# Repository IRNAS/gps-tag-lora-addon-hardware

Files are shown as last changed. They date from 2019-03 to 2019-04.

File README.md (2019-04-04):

irnas_logo

# gps-tag-lora-addon-hardware
Addon board with LoRa module for gps tag

Features:
* MCU STM32L072CZ
* USB
* on-board LDO regulator
* EEPROM with EUI Microchip 24AA02E48T-I/OT
* LoRa module E22-900M22S (SX1268)
* on-board SMT LoRa antenna

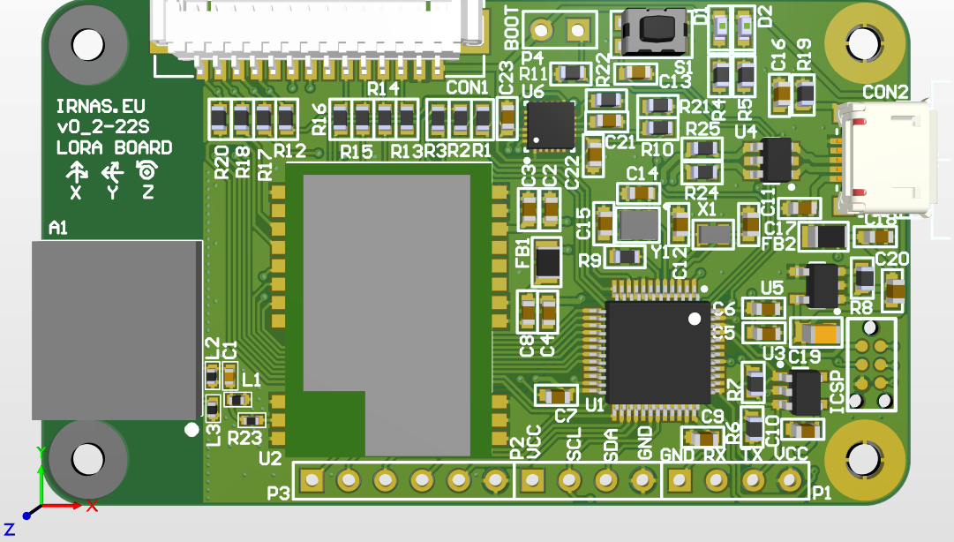
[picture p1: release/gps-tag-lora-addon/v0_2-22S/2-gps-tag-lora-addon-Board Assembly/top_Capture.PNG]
board_model


For all documentation please find the [latest relase](https://github.com/IRNAS/gps-tag-lora-addon-hardware/releases).

---
## License

All our projects are as usefully open-source as possible.

Hardware including documentation is licensed under [CERN OHL v.1.2. license](http://www.ohwr.org/licenses/cern-ohl/v1.2)

Firmware and software originating from the project is licensed under [GNU GENERAL PUBLIC LICENSE v3](http://www.gnu.org/licenses/gpl-3.0.en.html).

Open data generated by our projects is licensed under [CC0](https://creativecommons.org/publicdomain/zero/1.0/legalcode).

All our websites and additional documentation are licensed under [Creative Commons Attribution-ShareAlike 4 .0 Unported License] (https://creativecommons.org/licenses/by-sa/4.0/legalcode).

What this means is that you can use hardware, firmware, software and documentation without paying a royalty and knowing that you'll be able to use your version forever. You are also free to make changes but if you share these changes then you have to do so on the same conditions that you enjoy.

Koruza, GoodEnoughCNC and IRNAS are all names and marks of Institut IRNAS Rače. 
You may use these names and terms only to attribute the appropriate entity as required by the Open Licences referred to above. You may not use them in any other way and in particular you may not use them to imply endorsement or authorization of any hardware that you design, make or sell.

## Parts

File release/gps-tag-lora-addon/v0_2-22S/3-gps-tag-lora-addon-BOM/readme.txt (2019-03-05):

This folder includes:
- irnas readble BOM
- irnas simple sticker BOM

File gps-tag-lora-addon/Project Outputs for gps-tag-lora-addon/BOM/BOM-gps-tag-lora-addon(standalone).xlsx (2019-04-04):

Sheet: Part List Report
 | Component list |  |  | Arribada turtle gps tag Lora
 | Source Data From: | gps-tag-lora-addon.PrjPcb |  |  | Contact:
 | Project: | gps-tag-lora-addon.PrjPcb
 | Variant: | standalone |  |  |  |  |  |  | IRNAS
 | Report Date: | 04/04/2019 | 1:00 PM |  |  |  |  |  | www.irnas.eu
 | Print Date: | 2019-04-04 | 13:00:18
# | Manufacturer Part Number 1 | Manufacturer 1 | Description | Footprint | Designator | Quantity | Supplier 1 | Supplier Part Number 1 | Supplier Order Qty 1 | Supplier Stock 1 | Supplier Unit Price 1 | Supplier Subtotal 1 | Supplier Currency 1
1 | CC0805KKX7R8BB225 | Yageo | Multilayer Ceramic Capacitors MLCC - SMD/SMT 2.2uF 25V X7R 10% | CAP0805 | C19 | 1 | Farnell | 1458904 | 10 | 41834 | 0.37 | 3.73 | EUR
2 | 0603N331J500CT | Walsin Technologies | Cap Ceramic 330pF 50V C0G 5% SMD 0603 125C Paper T/R | CAP0603 | C16 | 1 | Farnell | 2496902 | 10 | 11708 | 0.08 | 0.75 | EUR
3 | TPS78326DDCT | Texas Instruments | IC REG LINEAR 2.6V 150MA SOT23-5 | SOT95P280X145-5N | U5 | 1 | Digi-Key | 296-35542-1-ND | 10 | 873 | 0.76 | 7.62 | EUR
4 | MPU-9250 | TDK InvenSense | IMU ACCEL/GYRO/MAG I2C/SPI 24QFN | QFN40P300X300X105_HS-25N | U6 | 1 | RSComponents | 883-7942P |  | 0
5 | C0603X103K5RECAUTO | TDK EPCOS | KEMET - C0603X103K5RECAUTO - CAP, MLCC, AEC-Q200, X7R, 0.01UF, 50V | CAP0603 | C22 | 1 | Farnell | 2760492 |  | 0
6 | STM32L072CZT6 | STMicroelectronics | IC MCU 32BIT 192KB FLASH 48LQFP | TSQFP50P900X900X160-48N | U1 | 1 | Mouser | 511-STM32L072CZT6 | 10 | 1017 | 3.13 | 31.30 | EUR
7 | USBLC6-2SC6 | STMicroelectronics | TVS DIODE 5.25VWM 17VC SOT23-6 | SOT95P280X145-6N | U4 | 1 | Farnell | 1269406 | 10 | 34596 | 0.38 | 3.83 | EUR
8 | BLM21PG221SN1D | Murata | FERRITE CHIP 220 OHM 0805 | IND0805 | FB1, FB2 | 2 | Farnell | 1515661 | 20 | 96225 | 0.06 | 1.20 | EUR
9 | LQG15HN4N3S02D | Murata | Inductor RF Chip Multi-Layer 4.3nH 0.3nH 100MHz 8Q-Factor Air 300mA 210mOhm DCR 0402 Paper T/R | IND0402 | L3 | 1 | Digi-Key | 490-6563-1-ND | 10 | 3502 | 0.05 | 0.54 | EUR
10 | GJM1555C1H2R2WB01D | Murata | Multilayer Ceramic Capacitors MLCC - SMD/SMT 0402 2.2pF 50Volts C0G +/-0.05pF | CAP0402 | C1 | 1 | Farnell | 2781431 | 10 | 0 | 0.23 | 2.30 | EUR
11 | GRM188R61H105KAALD | Murata | MURATA - GRM188R61H105KAALD - CAP, MLCC, X5R, 1UF, 50V, 0603 | CAP0603 | C3, C4, C5, C20 | 4 | Farnell | 1845736 | 40 | 0 | 0.41 | 16.42 | EUR
12 | GRM188R71C104KA01J | Murata | MURATA - GRM188R71C104KA01J - CAP, MLCC, X7R, 0.1UF, 16V, 0603 | CAP0603 | C2, C6, C7, C8, C9, C10, C13, C17, C18, C21, C23 | 11 | Farnell | 2688519 |  | 0
13 | GRM1885C1H200JA01D | Murata | MURATA - GRM1885C1H200JA01D - CAPACITOR, MLCC, C0G, 20PF, 50V, 0603 | CAP0603 | C11, C12, C14, C15 | 4 | Farnell | 2456108 | 40 | 0 | 0.09 | 3.64 | EUR
14 | MCWR06X27R0FTL | Multicomp | MULTICOMP MCWR06X27R0FTL Surface Mount Chip Resistor, Thick Film, MCWR Series, 27 ohm, 100 mW, 1%, 50 V | RES0603 | R24, R25 | 2 | Farnell | 2447316 | 20 | 74640 | 0.01 | 0.12 | EUR
15 | MC0.063W06031%1M | Multicomp | MULTICOMP - MC0063W060311M - RES, THICK FILM, 1M, 1%, 0.063W, 0603 | RES0603 | R19 | 1 | Farnell | 9330410 | 10 | 0 | 0.08 | 0.80 | EUR
16 | MCMR06X103JTL | Multicomp | MULTICOMP - MCMR06X103 JTL - RES, CERAMIC, 10K, 5%, 0.1W, 0603 | RES0603 | R8, R11, R22 | 3 | Farnell | 2073356 |  | 0
17 | MCMR06X471JTL | Multicomp | MULTICOMP - MCMR06X471 JTL - RES, CERAMIC, 470R, 5%, 0.1W, 0603 | RES0603 | R4, R5 | 2 | Farnell | 2073513 | 20 | 3705 | 0.01 | 0.12 | EUR
18 | MCMR06X4701FTL | Multicomp | MULTICOMP - MCMR06X4701FTL - RES, CERAMIC, 4K7, 1%, 0.1W, 0603 | RES0603 | R6, R7 | 2 | Farnell | 2073509 | 20 | 21438 | 0.01 | 0.22 | EUR
19 | MCWR06X2200FTL | Multicomp | MULTICOMP - MCWR06X2200FTL - RES, THICK FILM, 220R, 1%, 0.1W, 0603 | RES0603 | R9 | 1 | Farnell | 2447298 | 10 | 114827 | 0.01 | 0.06 | EUR
20 | MCMR04X000PTL | Multicomp | RESISTOR, 0402, 0R, ANTI SULFURATION | RES0402 | R23 | 1 | Farnell | 2072513 | 10 | 222051 | 0.01 | 0.07 | EUR
21 | 53261-1471 | Molex | 1.25mm (.049") Pitch PicoBlade Header, Surface Mount, Right Angle, Lead-free, 14 Circuits | 53261-1471 | CON1 | 1 | Farnell | 1125364 | 10 | 2483 | 2.04 | 20.36 | EUR
22 | 24AA02E48T-I/OT | Microchip | MICROCHIP 24AA02E48T-I/OT EEPROM, EUI-48 Node Identity, 2 Kbit, 2 BLK (128K x 8bit), 400 kHz, I2C, SOT-23, 5 Pins | SOT95P280X145-5N | U3 | 1 | Farnell | 1688855 | 10 | 10048 | 0.20 | 2.00 | EUR
23 | KMR221NGLFS | ITT C&K | SWITCH TACTILE SPST-NO 0.05A 32V | SW | S1 | 1 | Farnell | 2845727 | 10 | 2438 | 0.34 | 3.40 | EUR
24 | HSMS-C190 | Broadcom | BROADCOM LIMITED - HSMS-C190 - LED, RED, 10MCD, 626NM | LED0603 | D1, D2 | 2 | Farnell | 2497356 | 20 | 0 | 0.15 | 2.90 | EUR
25 | CR0603-J/-000ELF | Bourns | BOURNS - CR0603-J/-000ELF - RES, THICK FILM, 0R, 5%, 0.1W, 0603 | RES0603 | R1, R2, R3, R10, R12, R17, R18, R20, R21 | 9 | Farnell | 2008343 | 90 | 36437 | 0.01 | 1.25 | EUR
26 | SR42I010-R | Antenova | Antenna SMD -4dBi Gain 870MHz/928MHz Automotive 7-Pin SMD T/R | LORA_PCB_ANTENNA | A1 | 1 | Mouser | 237-SR42I010-R | 10 | 2899 | 1.69 | 16.90 | EUR
27 | ABM10-16.000MHZ-D30-T3 | Abracon | 16MHz ±20ppm Crystal 10pF 150 Ohm -40°C ~ 85°C Surface Mount 4-SMD, No Lead (DFN, LCC) | CRY2.5X2 | Y1 | 1 | Farnell | 2467762 | 10 | 1307 | 1.17 | 11.67 | EUR
28 | ABS06-107-32.768KHZ-T | Abracon | 32.768KHz 4pF Max. ESR 81 Kohms | CRY2X1.2 | X1 | 1 | Farnell | 2467860 | 10 | 5308 | 0.77 | 7.66 | EUR
29 |  |  |  | microUSB-CHINA | CON2 | 1
30 |  |  |  | E22-900M22S | U2 | 1
 |  |  |  |  |  | 61 |  |  | 430 |  |  | 138.86673
Approved |  |  |  | Notes
 |  |  |  | pcs: |  | 10 |  | Total |  | 138.86673 |  | EUR
 |  |  |  |  |  |  |  | Price for 1pcs |  | 13.89 |  | EUR

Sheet: Project Information
Project Full Path | C:\Users\vojislav\OneDrive\IRNAS-Common\_NEW-IRNAS-COMMON\opencollar-io\Electronics\gps-tag-lora-addon-hardware\gps-tag-lora-addon\gps-tag-lora-addon.PrjPcb
Project Filename | gps-tag-lora-addon.PrjPcb
Variant Name | standalone
Data-Source Filename | gps-tag-lora-addon.PrjPcb
Data-Source Full Path | C:\Users\vojislav\OneDrive\IRNAS-Common\_NEW-IRNAS-COMMON\opencollar-io\Electronics\gps-tag-lora-addon-hardware\gps-tag-lora-addon\gps-tag-lora-addon.PrjPcb
Title | BOM for Variant [standalone] of Project [gps-tag-lora-addon.PrjPcb] (PCB Document : gps-tag-lora-addon.PcbDoc)
Total Quantity | 61
Report Time | 1:00 PM
Report Date | 04/04/2019
Report Date & Tine | 04/04/2019 1:00 PM
Output Name | BOM
Output Type | BOM_PartType
Output Generator Name | BOM
Output Generator Description | Bill of Materials

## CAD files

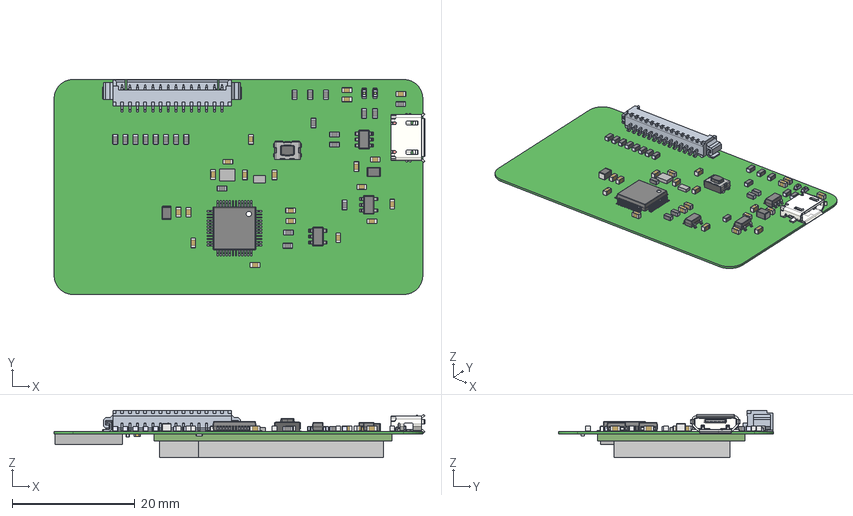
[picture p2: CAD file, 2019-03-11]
gps-tag-lora-addon/Project Outputs for gps-tag-lora-addon/ExportSTEP/gps-tag-lora-addon(standalone).step
60.3 x 35.0 x 7.69 mm
R0603 x 21
Mid_Body
Open_CASCADE_STEP_translator_6.8_3.2.1 x 2
Mark
Open_CASCADE_STEP_translator_6.8_1.1.1 x 3
Leader x 64
Open_CASCADE_STEP_translator_6.8_6.1.1
Extruded x 7
Open_CASCADE_STEP_translator_6.8_18.1
Open_CASCADE_STEP_translator_6.8_18.2.1
User_Library-Switch-CK-KMR2_Button
User_Library-Switch-CK-KMR2_Boitier
User_Library-Switch-CK-KMR2_Tole
User_Library-Switch-CK-KMR2_Pads
Open_CASCADE_STEP_translator_6.8_1.1.2
Open_CASCADE_STEP_translator_6.8_1.2.1
Open_CASCADE_STEP_translator_6.8_2.1.1 x 2
Open_CASCADE_STEP_translator_6.8_2.1.2 x 2
Open_CASCADE_STEP_translator_6.8_2.2.1 x 2
LED_SMD_0603 x 2
USB_MICRO_SMD
C_SMD_0603 x 20
Open_CASCADE_STEP_translator_6.8_4.1.1
Open_CASCADE_STEP_translator_6.8_4.1.2
Open_CASCADE_STEP_translator_6.8_4.2.1

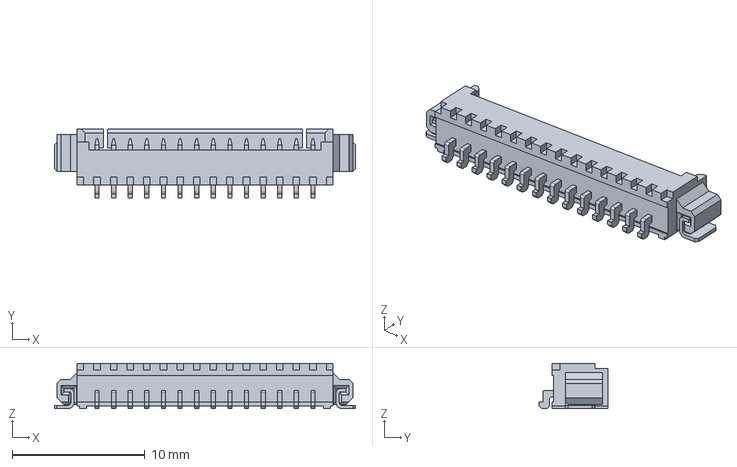
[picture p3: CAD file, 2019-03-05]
gps-tag-lora-addon/step/532611471.stp
22.6 x 5.20 x 3.40 mm

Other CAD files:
gps-tag-lora-addon/Project Outputs for gps-tag-lora-addon/ExportSTEP/gps-tag-lora-addon.step
release/gps-tag-lora-addon/v0_1/5-gps-tag-lora-addon-3D/gps-tag-lora-addon.step

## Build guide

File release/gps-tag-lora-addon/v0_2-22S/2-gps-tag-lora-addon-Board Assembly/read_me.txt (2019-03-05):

Place following files here:

- Mechanical Drawing (Board dimensions, holes position, ..)
- TOP and BOTTOM Assembly Drawing (Component position with Reference Designator)
- Pick and Place csv
- 3D Model pictures TOP and BOTTOM

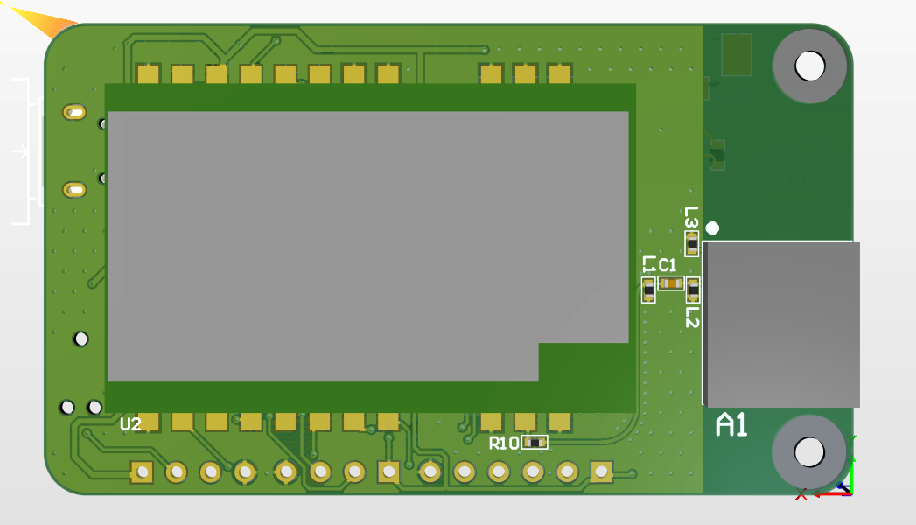
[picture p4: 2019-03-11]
release/gps-tag-lora-addon/v0_2/2-gps-tag-lora-addon-Board Assembly/bot_Capture.PNG

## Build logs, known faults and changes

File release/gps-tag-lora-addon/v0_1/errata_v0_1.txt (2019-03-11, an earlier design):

Schematic is designed for Lora module E22-900M22S but the footprint is for E22-900M30S. The difference i because there is one pins which is VCC instead of GND

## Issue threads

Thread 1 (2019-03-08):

Wrong lora module

VojislavM, 2019-03-08:
Schematic is designed for Lora module E22-900M22S but the footprint is for E22-900M30S. The difference i because there is one pins which is VCC instead of GND

SloMusti, 2019-03-15:
Resolved in 083d871dd6b80ef38df3ab4144fabe534fb557b0

Closed 2019-03-15.

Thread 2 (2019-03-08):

boot pin pull-down

VojislavM, 2019-03-08:
Add 10k pull-down resistor to boot pin and jumper just to VCC

SloMusti, 2019-03-15:
Resolved in 083d871dd6b80ef38df3ab4144fabe534fb557b0

Closed 2019-03-15.

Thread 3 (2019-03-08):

I2C pins

VojislavM, 2019-03-08:
Move I2C pins form P6 and P7 to P8 and P9

VojislavM, 2019-03-08:
This way the bard is compatible with previous design

SloMusti, 2019-03-15:
Resolved in 083d871dd6b80ef38df3ab4144fabe534fb557b0

Closed 2019-03-15.

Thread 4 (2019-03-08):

Lora module BUSY pin

VojislavM, 2019-03-08:
Connect BUSY pin form the lora module to the MCU

SloMusti, 2019-03-15:
Resolved in 083d871dd6b80ef38df3ab4144fabe534fb557b0

Closed 2019-03-15.

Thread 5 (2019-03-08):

SPI pins problem

VojislavM, 2019-03-08:
SPI pins on wrong pins
SPI SCK PA5
SPI MISO PA6
SPI MOSI PA7

SloMusti, 2019-03-15:
Resolved in 083d871dd6b80ef38df3ab4144fabe534fb557b0

Closed 2019-03-15.

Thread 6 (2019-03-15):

LDO regulator power-draw

SloMusti, 2019-03-15:
The LDO regulator draws an undesired amount of power in the given situations:

 * 3V3 power applied, no 5V input - 40uA
 * 5V  power applied, LDO curernt is high - 100uA+

Replacing the LDO with a lower power one from TI tps78326 resolves one scenario, where power draw when 5V power is applied is reduced to about 1uA, however when 3V3 power is applied, the draw is 730uA

VojislavM, 2019-04-04:
done in the v0.2-22S

Closed 2019-04-04.

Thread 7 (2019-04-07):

Add battery connector

SloMusti, 2019-04-07:
Add pins to connect battery or other input voltage, currently the only pins to do are either directly for 3V3 or 5V iva USB port.

VojislavM, 2019-04-08:
Battery connector should be placed on the input of the U5 regulator that has 2.6V on output.
Currently there is power form USB connected to the U5 input.
* Do we need to add battery charger?
* Add protection between battery and USB protection?
* connector type?

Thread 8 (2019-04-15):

Add battery voltage monitoring

SloMusti, 2019-04-15:
Enable battery voltage measurement

VojislavM, 2019-04-19:
this can be done over simple resistor devider providing signal to the analog pin of the MCU.
Will be added in the next version

SloMusti, 2019-04-19:
Note that may consume too much power, consider more power optimal solutions

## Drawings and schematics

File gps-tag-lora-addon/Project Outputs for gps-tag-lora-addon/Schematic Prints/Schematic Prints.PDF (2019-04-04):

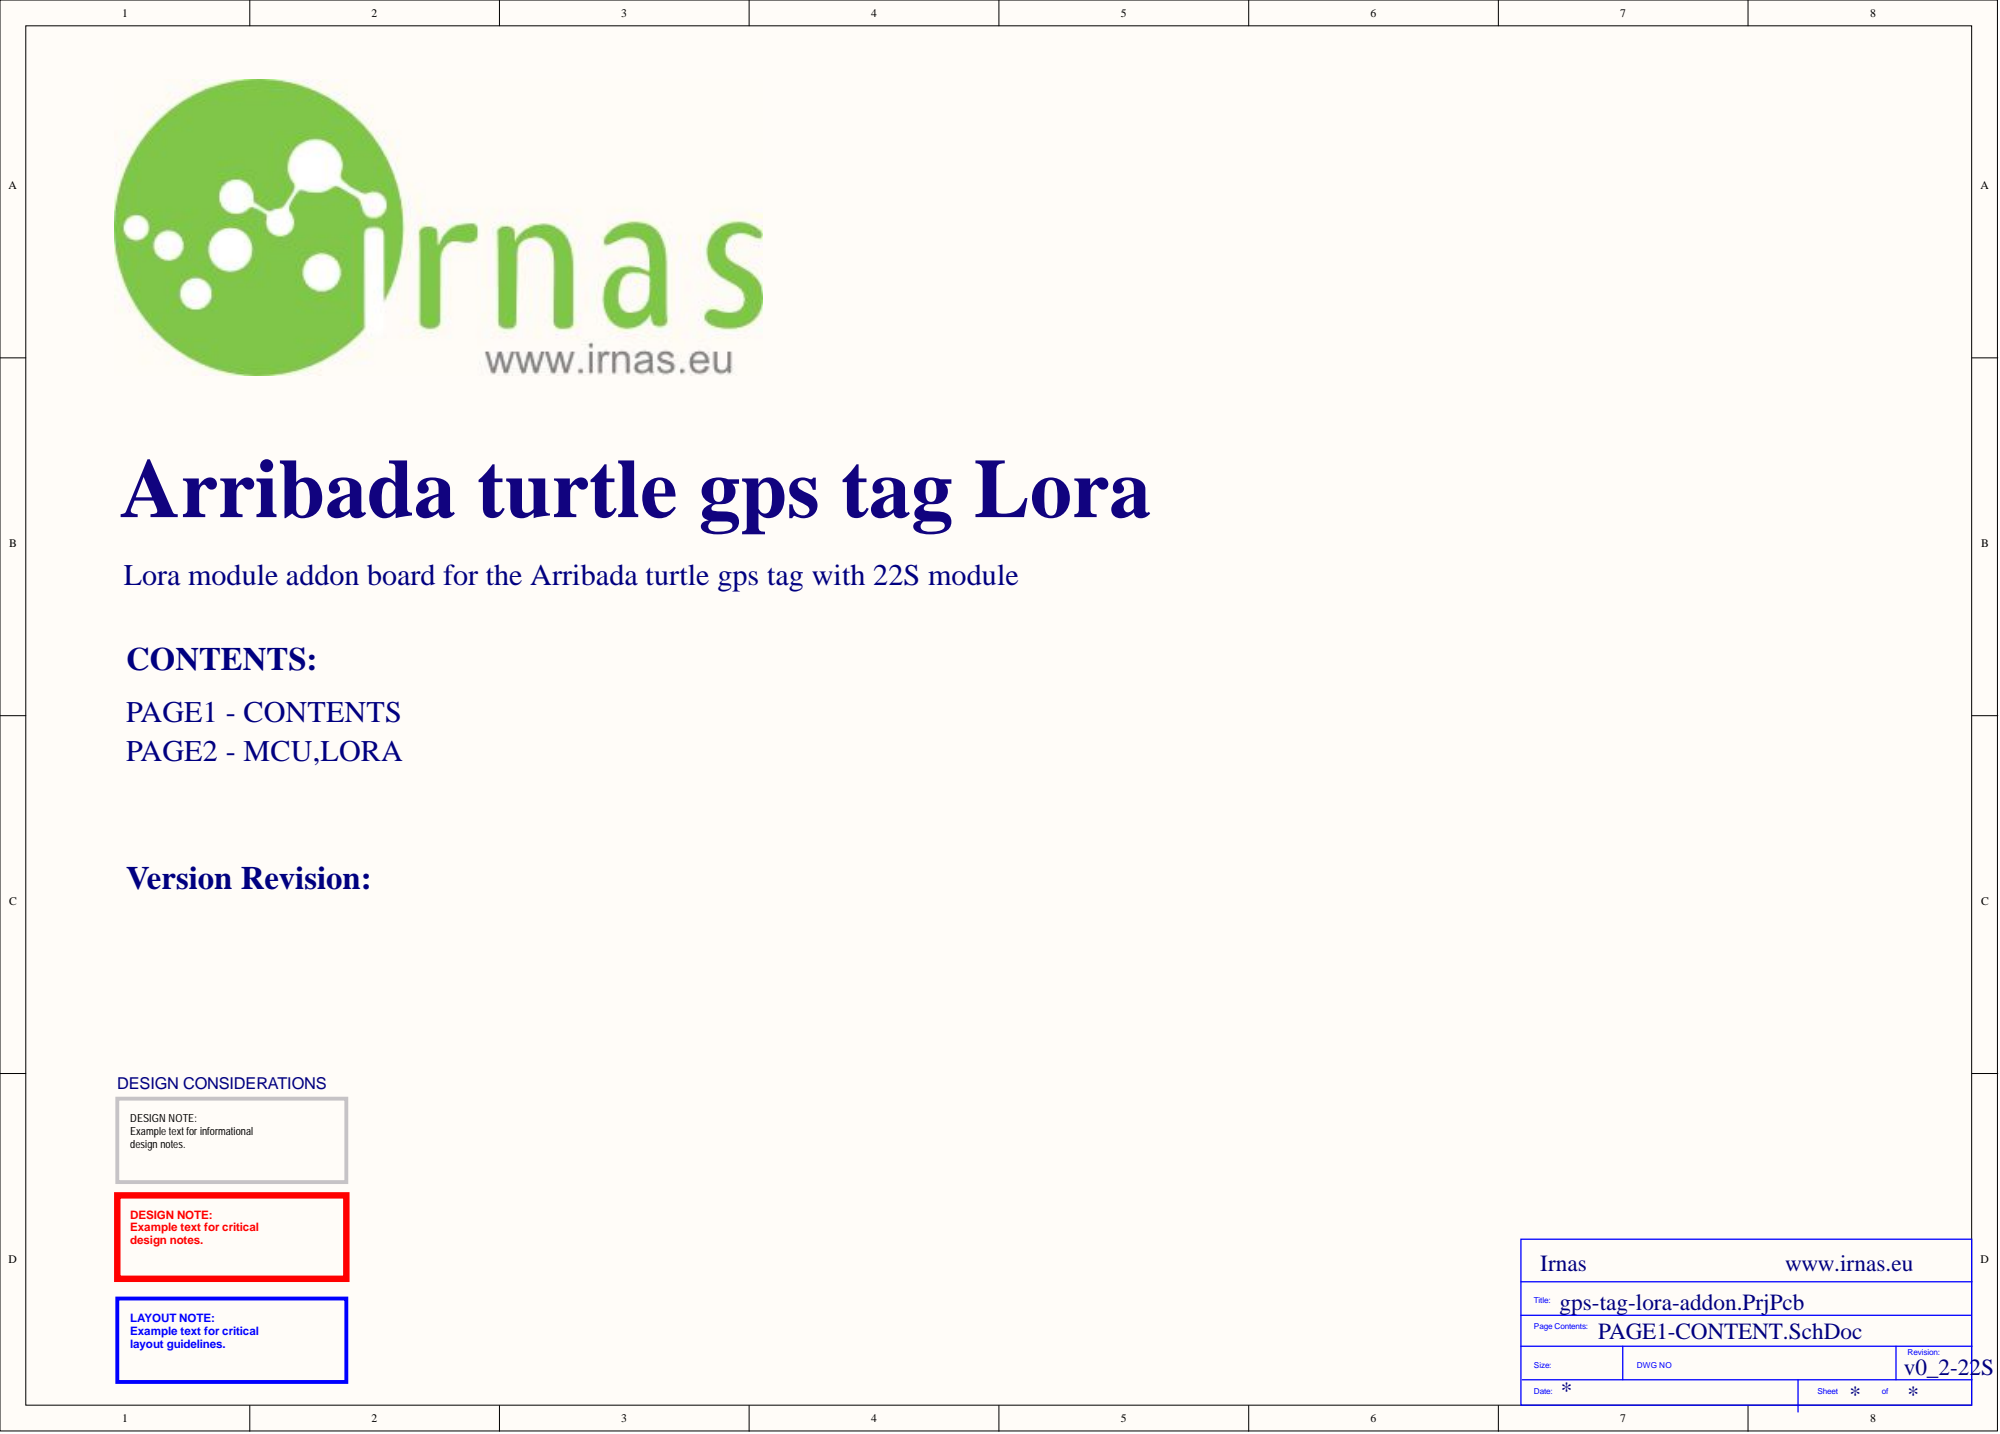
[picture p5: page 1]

Arribada turtle gps tag Lora

Lora module addon board for the Arribada turtle gps tag with 22S module

DESIGN NOTE:
Example text for informational
design notes.

Example text for critical

gps-tag-lora-addon.PrjPcb
PAGE1-CONTENT.SchDoc

LAYOUT NOTE:
layout guidelines.

Size: | DWG NO | Revision:

* Date: | * * Sheet of

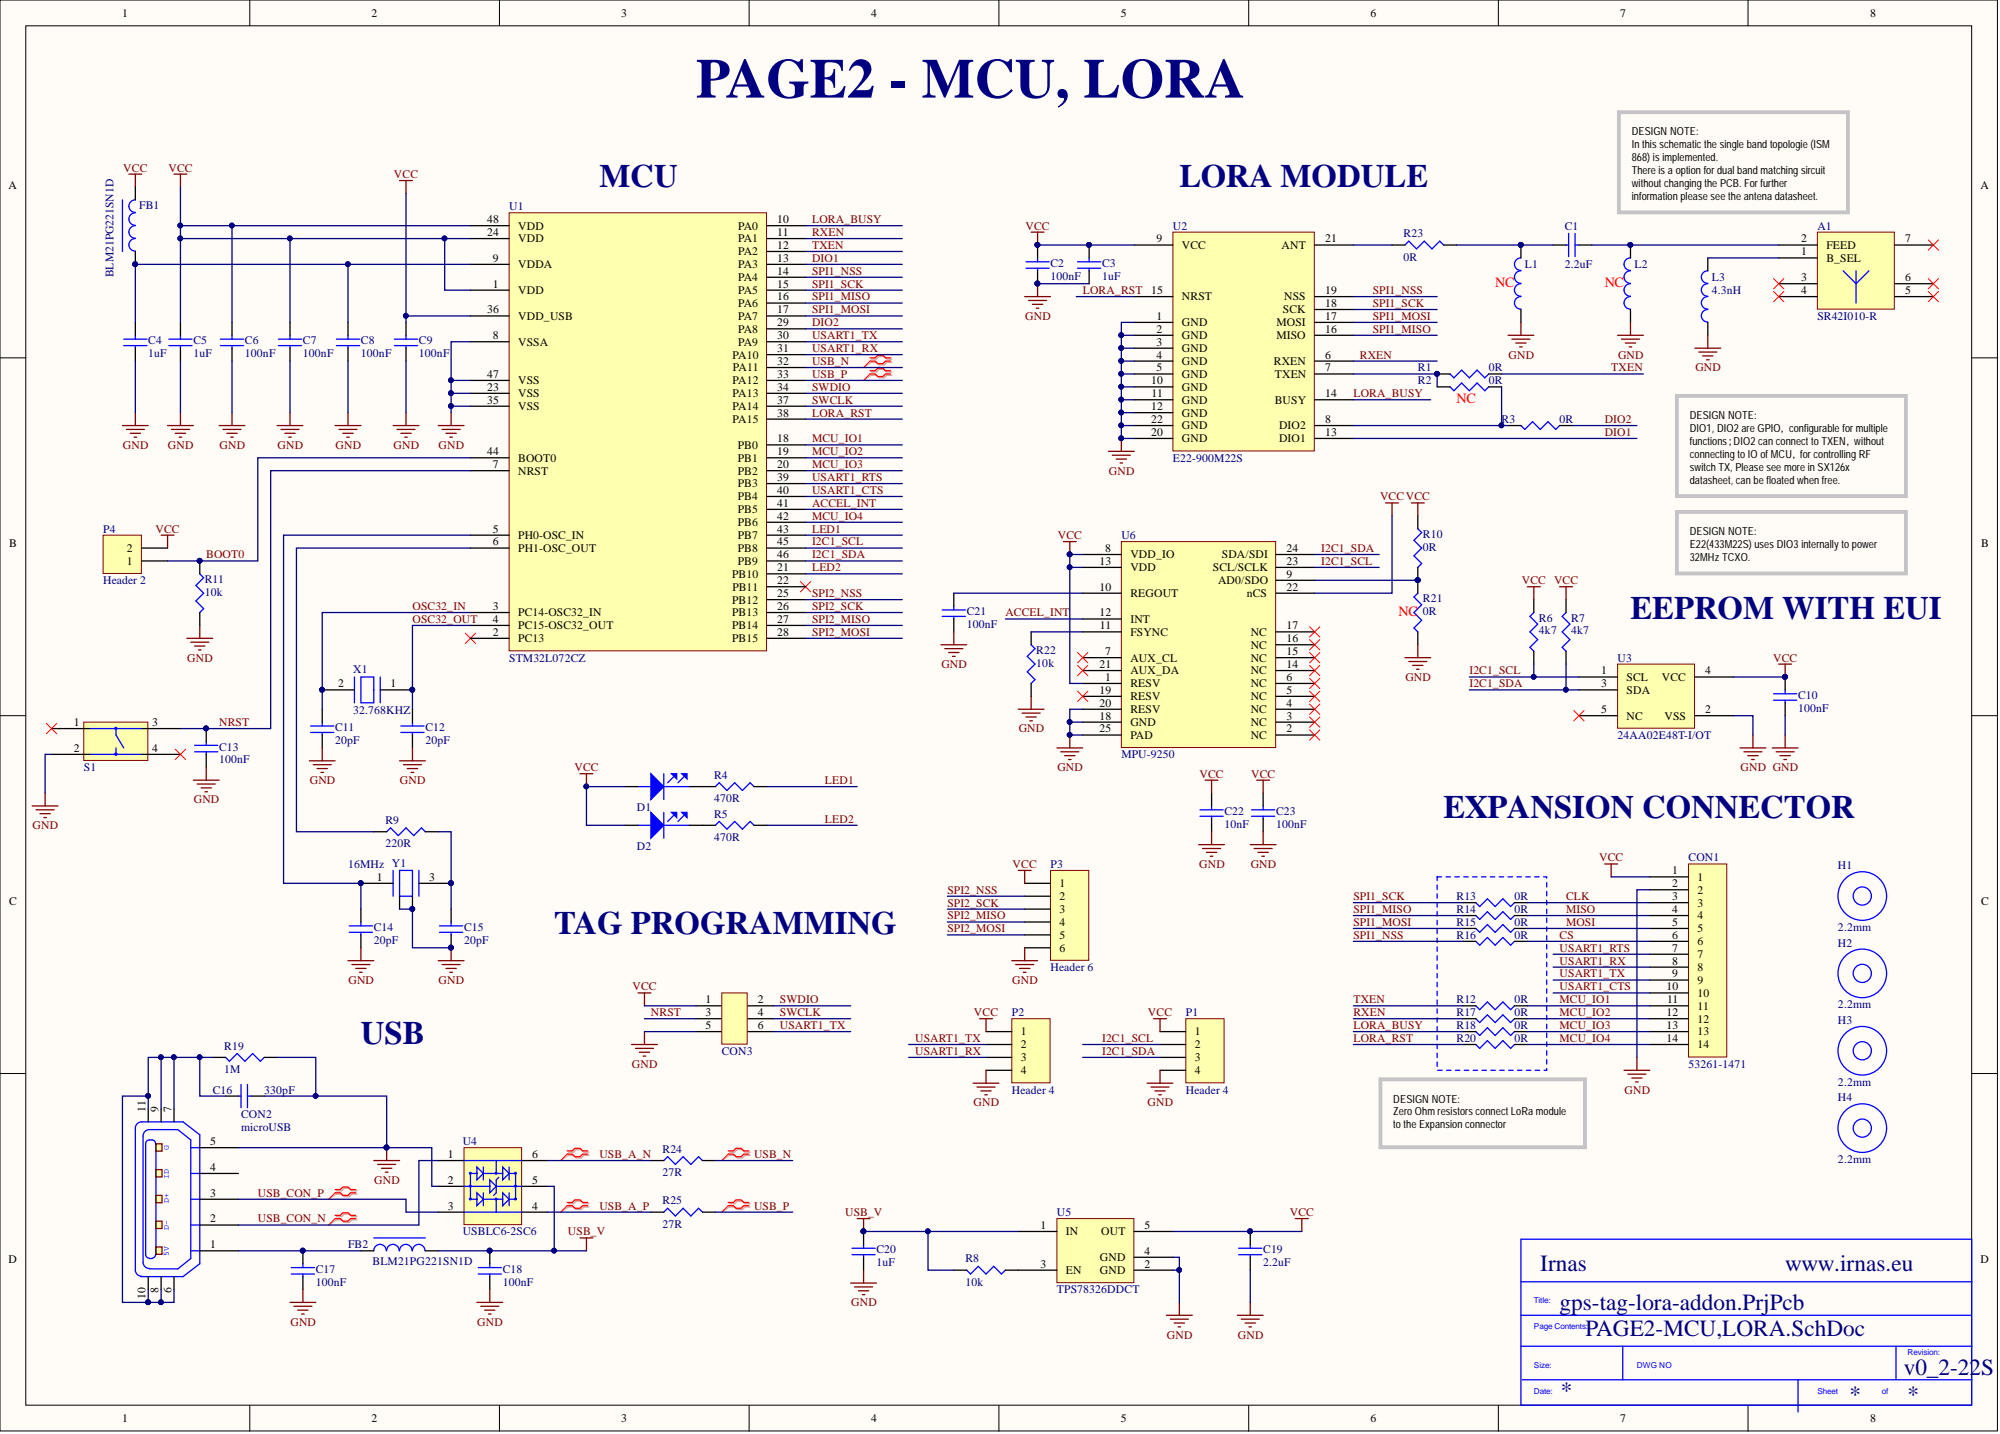
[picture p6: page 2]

DESIGN NOTE:
In this schematic the single band topologie (ISM
868) is implemented.
There is a option for dual band matching sircuit
without changing the PCB. For further
information please see the antena datasheet.

VDD 24

VDD 1

VSSA 8

GND 2 | SPI1_MISO

VSS 47
VSS 23

DIO1, DIO2 are GPIO，configurable for multiple
functions；DIO2 can connect to TXEN，without
connecting to IO of MCU，for controlling RF
switch TX, Please see more in SX126x
datasheet, can be floated when free.

PH0-OSC_IN 5

E22(433M22S) uses DIO3 internally to power
32MHz TCXO.
EEPROM WITH EUI

VDD 13 | I2C1_SCL

R11 10k NRST | OSC32_IN

PC14-OSC32_IN 3

OSC32_OUT | PC15-OSC32_OUT 4

Zero Ohm resistors connect LoRa module
to the Expansion connector

USB_CON_N

gps-tag-lora-addon.PrjPcb
PAGE2-MCU,LORA.SchDoc

Size: | DWG NO | Revision:

* Date: | * * Sheet of

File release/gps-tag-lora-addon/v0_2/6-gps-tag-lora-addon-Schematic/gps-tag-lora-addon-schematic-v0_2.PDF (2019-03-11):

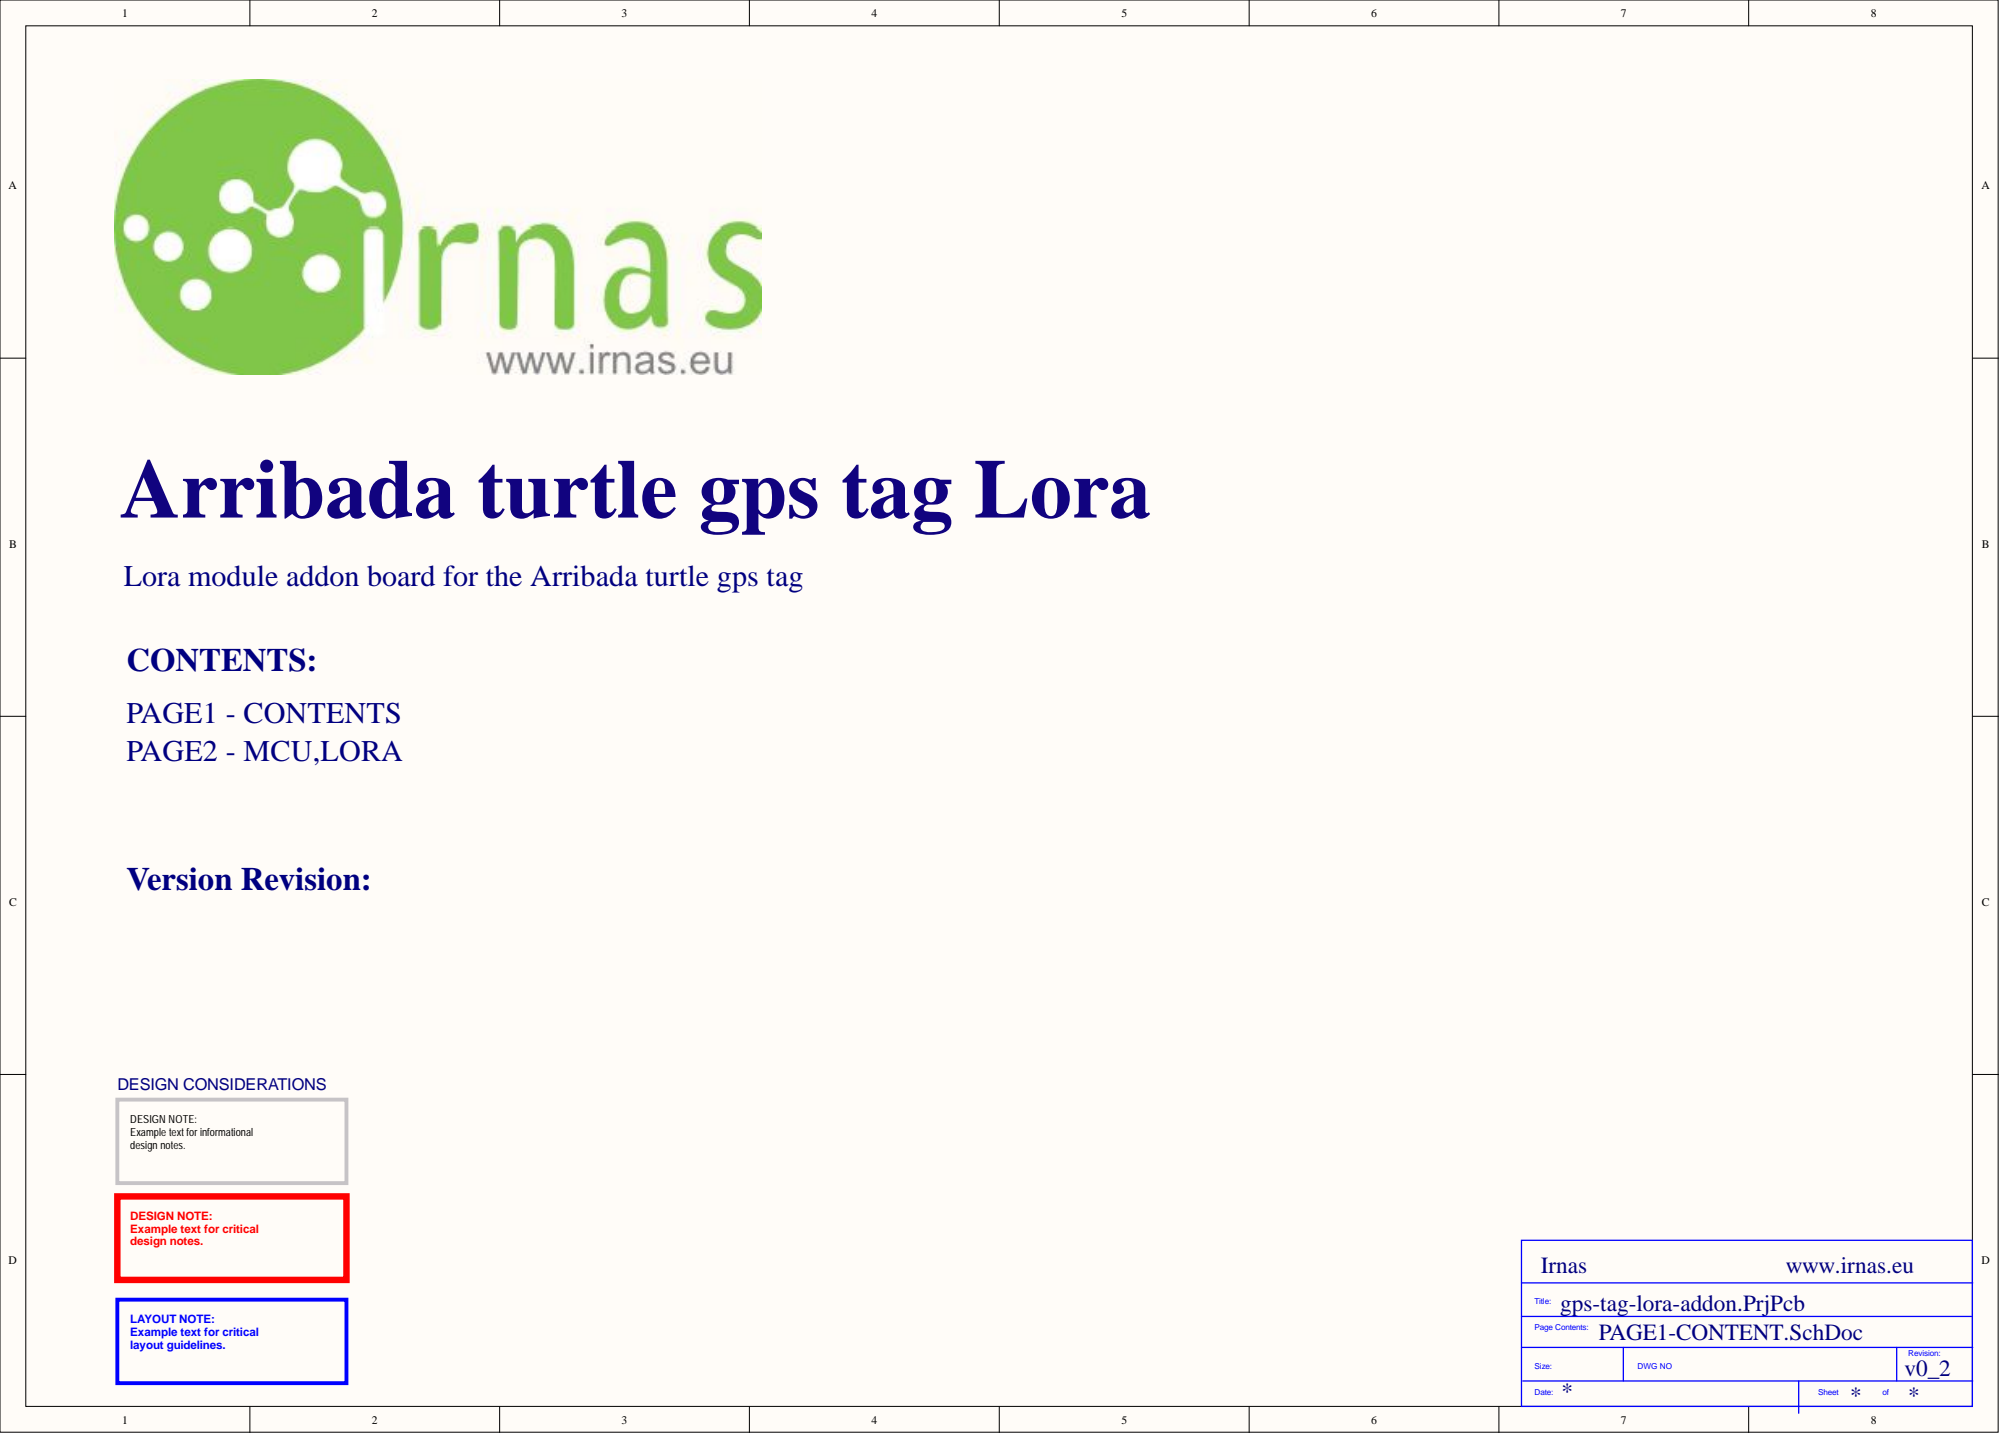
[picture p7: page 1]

Arribada turtle gps tag Lora

Lora module addon board for the Arribada turtle gps tag

DESIGN NOTE:
Example text for informational
design notes.

Example text for critical

gps-tag-lora-addon.PrjPcb
PAGE1-CONTENT.SchDoc

LAYOUT NOTE:
layout guidelines.

Size: | DWG NO | Revision: v0_2

* Date: | * * Sheet of

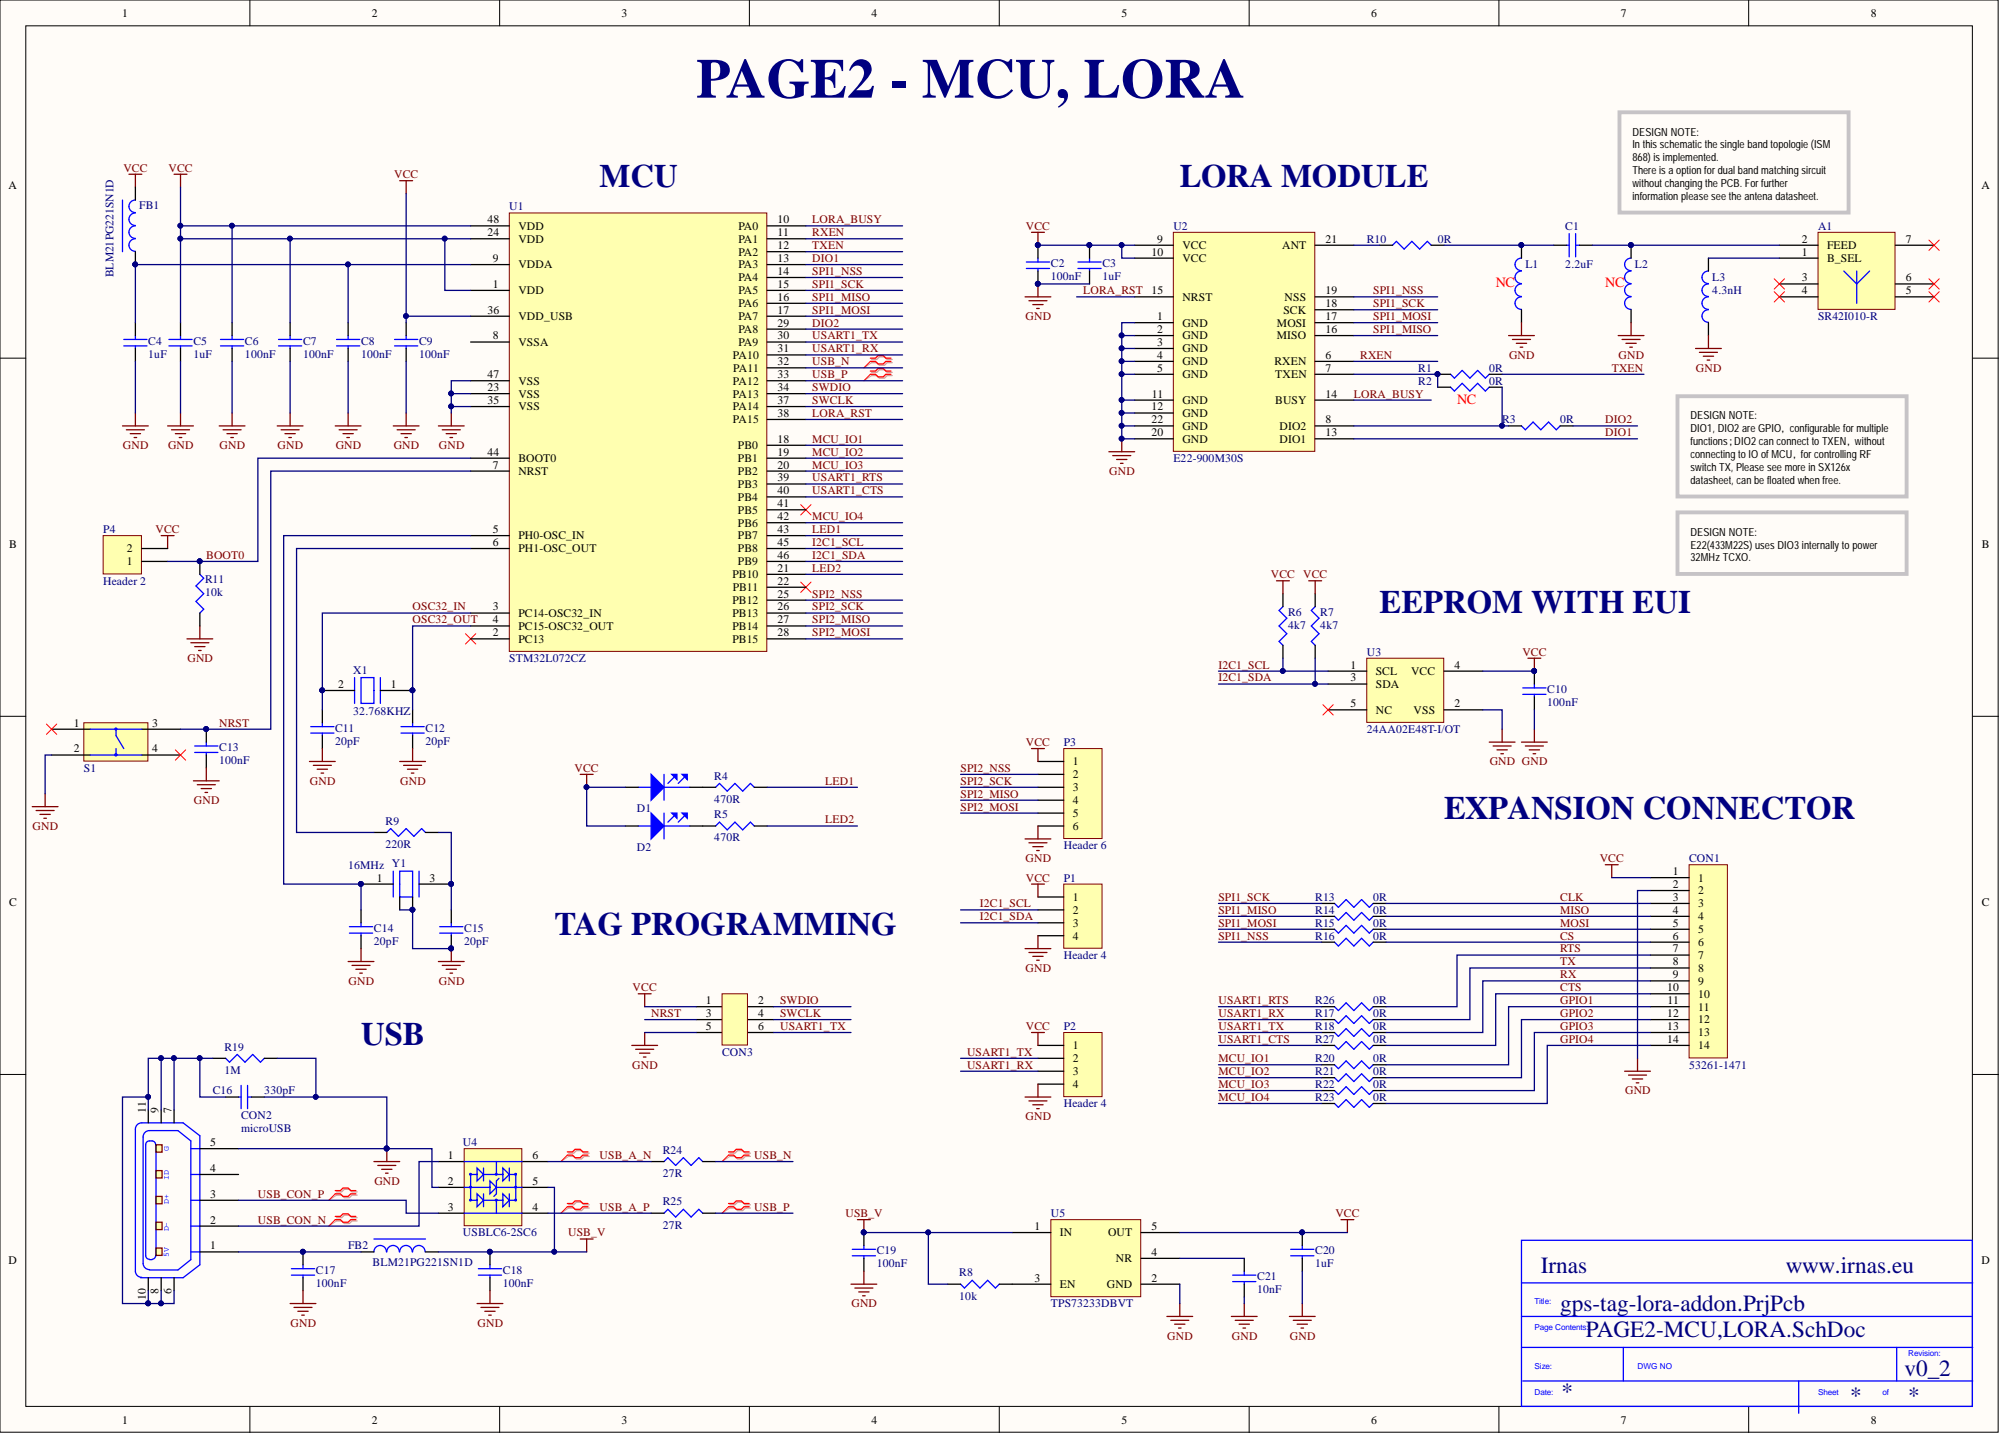
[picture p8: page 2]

DESIGN NOTE:
In this schematic the single band topologie (ISM
868) is implemented.
There is a option for dual band matching sircuit
without changing the PCB. For further
information please see the antena datasheet.

VDD 24

VDD 1

DIO1, DIO2 are GPIO，configurable for multiple
functions；DIO2 can connect to TXEN，without
connecting to IO of MCU，for controlling RF
switch TX, Please see more in SX126x
datasheet, can be floated when free.

PH0-OSC_IN 5

E22(433M22S) uses DIO3 internally to power
32MHz TCXO.

R11 10k NRST | OSC32_IN

PC14-OSC32_IN 3

OSC32_OUT | PC15-OSC32_OUT 4

2 2
3 3 4 4 5 5 6 6 7 7

TX | | 8 8
RX | | 9 9
CTS | | 10 10

3 | GND

USB_CON_P | 2

USB_CON_N

gps-tag-lora-addon.PrjPcb
PAGE2-MCU,LORA.SchDoc

Size: | DWG NO | Revision: v0_2

* Date: | * * Sheet of

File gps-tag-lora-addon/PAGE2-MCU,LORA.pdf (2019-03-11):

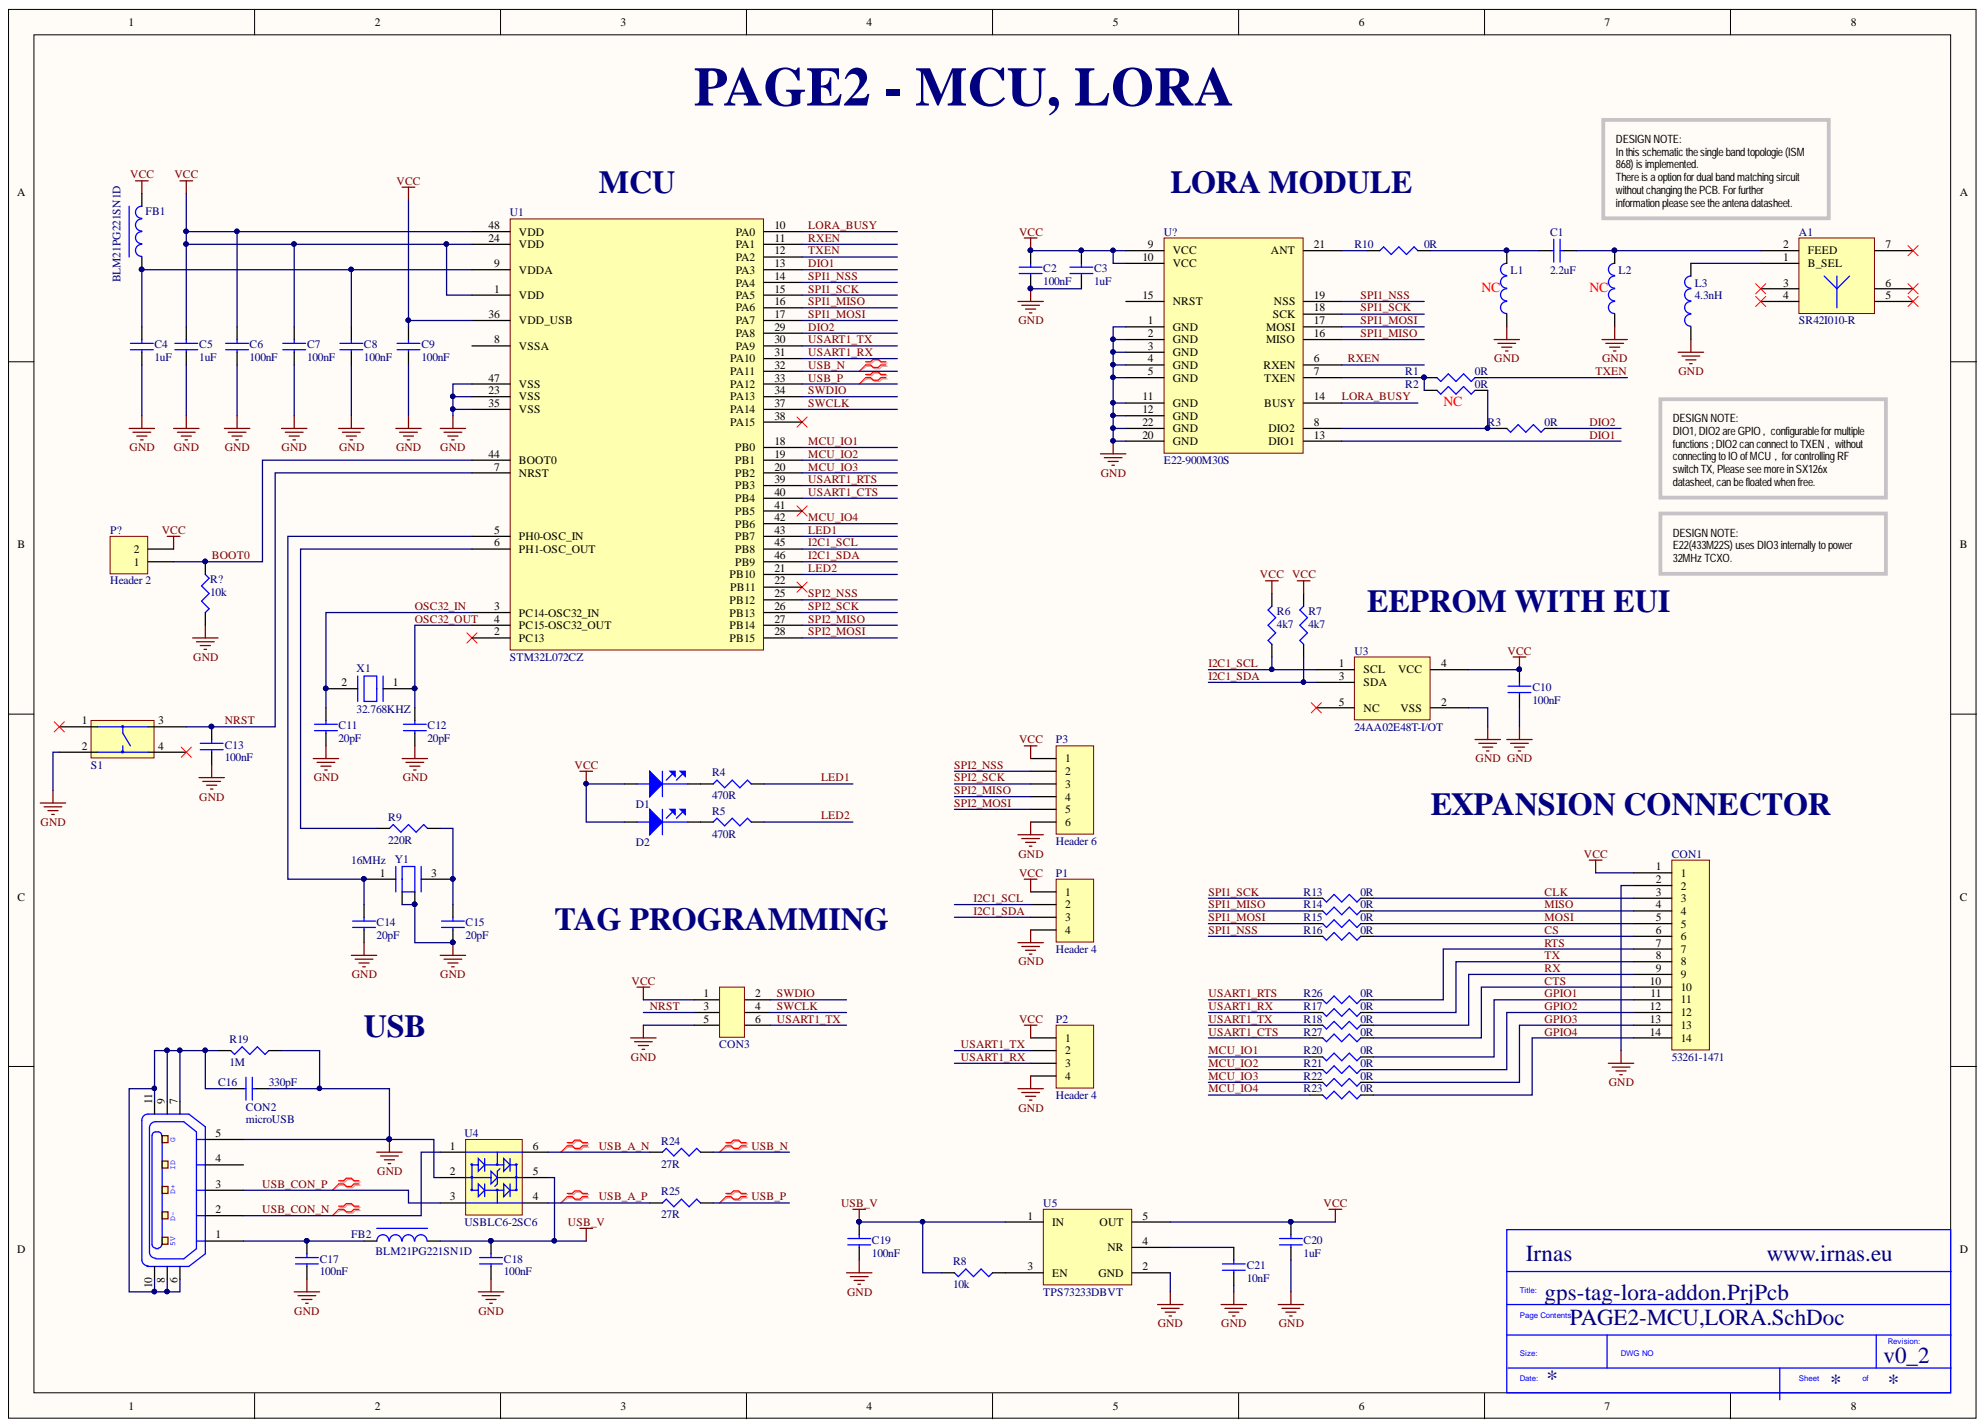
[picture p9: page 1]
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

PH0-OSC_IN 5

E22(433M22S) uses DIO3 internally to power
32MHz TCXO.

R? 10k NRST | OSC32_IN

OSC32_OUT | PC15-OSC32_OUT 4

PC14-OSC32_IN 3

32.768KHZ C11 | C12

TX | | 8 8
RX | | 9 9
CTS | | 10 10
GPIO1 | | 11 11
GPIO2 | | 12 12
GPIO3 | | 13 13

3 | GND

USB_CON_P | 2

USB_CON_N | USB_V

gps-tag-lora-addon.PrjPcb
PAGE2-MCU,LORA.SchDoc

Size: | DWG NO | Revision: v0_2

* Date: | * * Sheet of

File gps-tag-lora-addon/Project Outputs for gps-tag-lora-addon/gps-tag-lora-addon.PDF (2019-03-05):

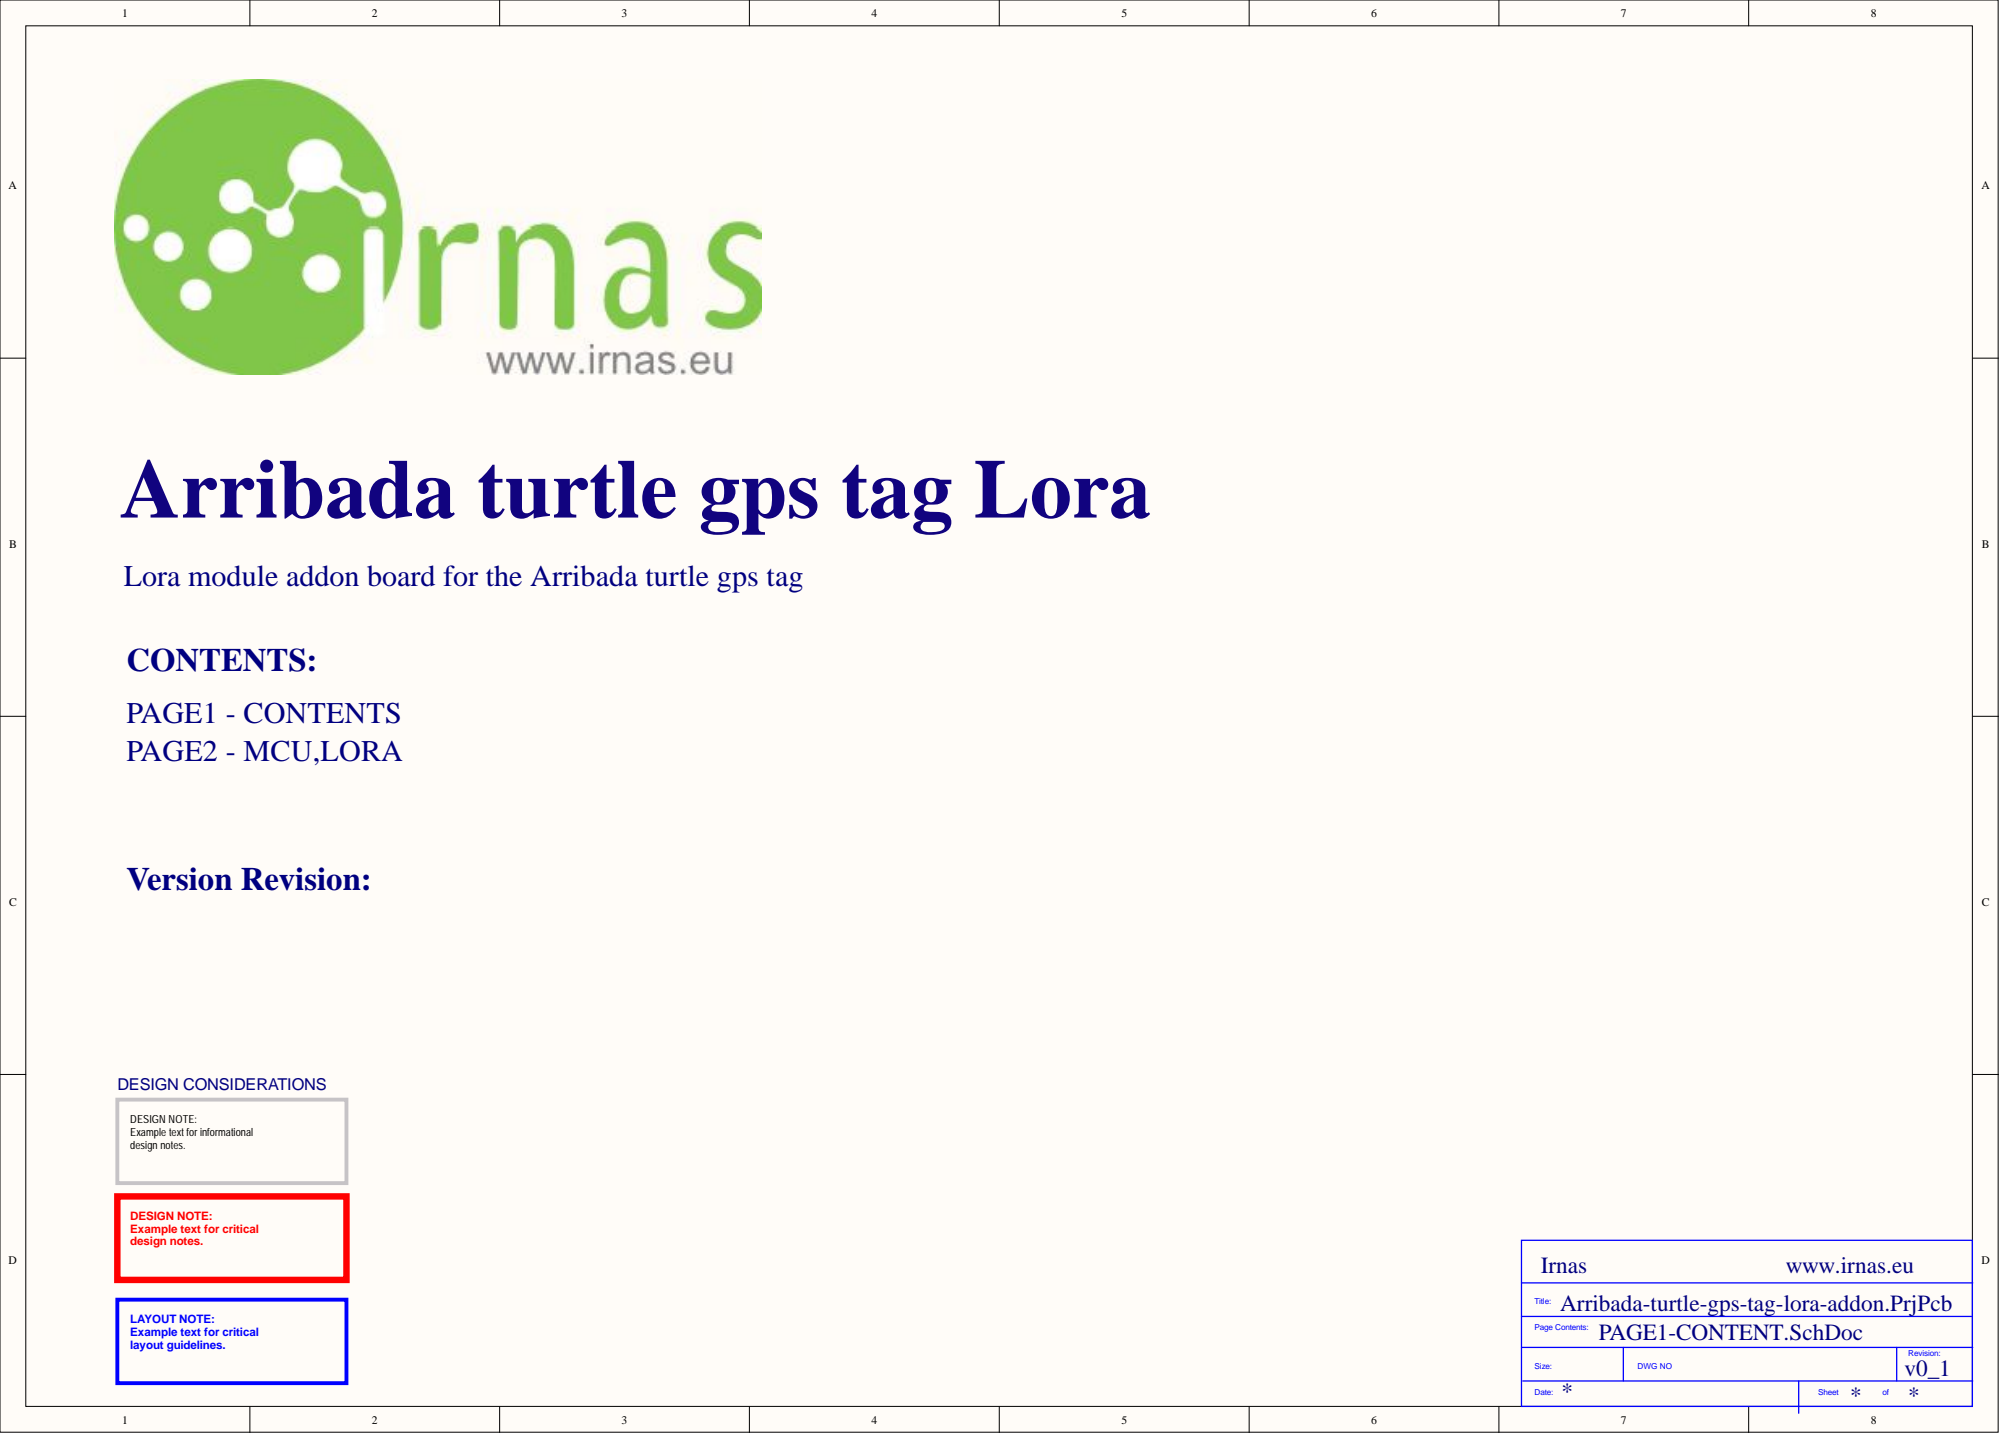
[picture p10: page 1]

Arribada turtle gps tag Lora

Lora module addon board for the Arribada turtle gps tag

DESIGN NOTE:
Example text for informational
design notes.

Example text for critical

Arribada-turtle-gps-tag-lora-addon.PrjPcb
PAGE1-CONTENT.SchDoc

LAYOUT NOTE:
layout guidelines.

Size: | DWG NO | Revision: v0_1

* Date: | * * Sheet of

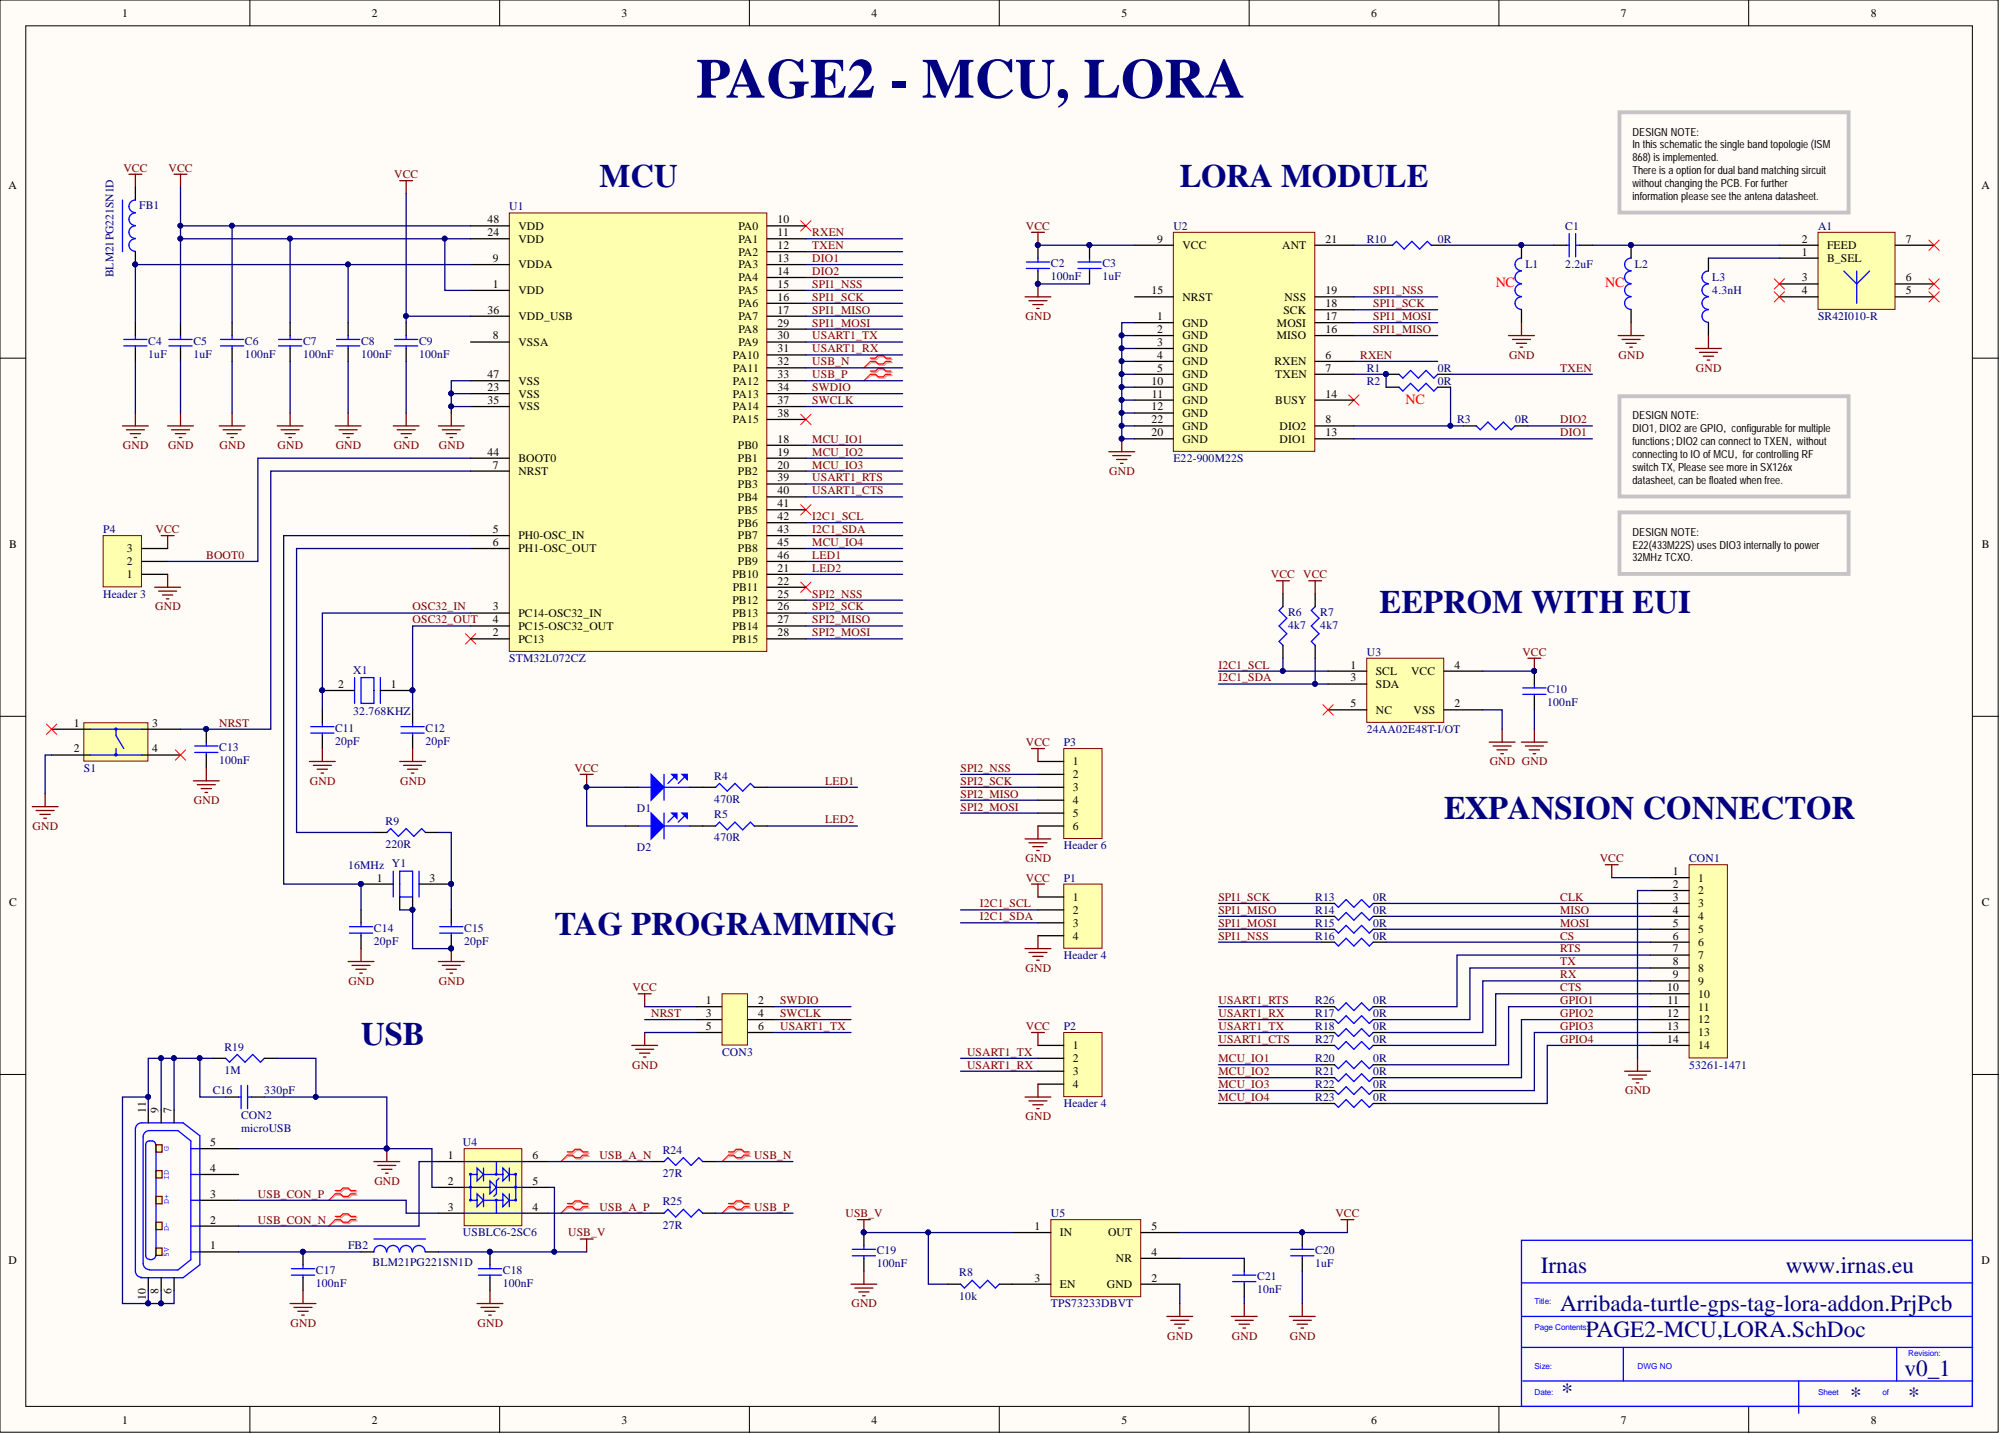
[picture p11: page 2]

DESIG
In thi
s implemented.
There i
without changing the PCB. For further information please see the antena datasheet. DESIGN NOTE: DIO1, DIO2 are GPIO，configurable for multiple

ingle band topologie (ISM
c the s

s a option for dual band matching s

functions
connecting to IO of MC

DIO2 can connect to TXEN

switch TX, Please see more in SX126x
datasheet, can be floated when free. DESIGN NOTE:

NRST | | OSC3 2 _IN

OSC3 2 _ O U | T 4

AVCC GND GND VCC

T X | | 8
RX | | 9
CT S | | 1 0

USB_CO N _ P | D | 123

S i z e : | DWG N O | R e v i s i o n : v0_1

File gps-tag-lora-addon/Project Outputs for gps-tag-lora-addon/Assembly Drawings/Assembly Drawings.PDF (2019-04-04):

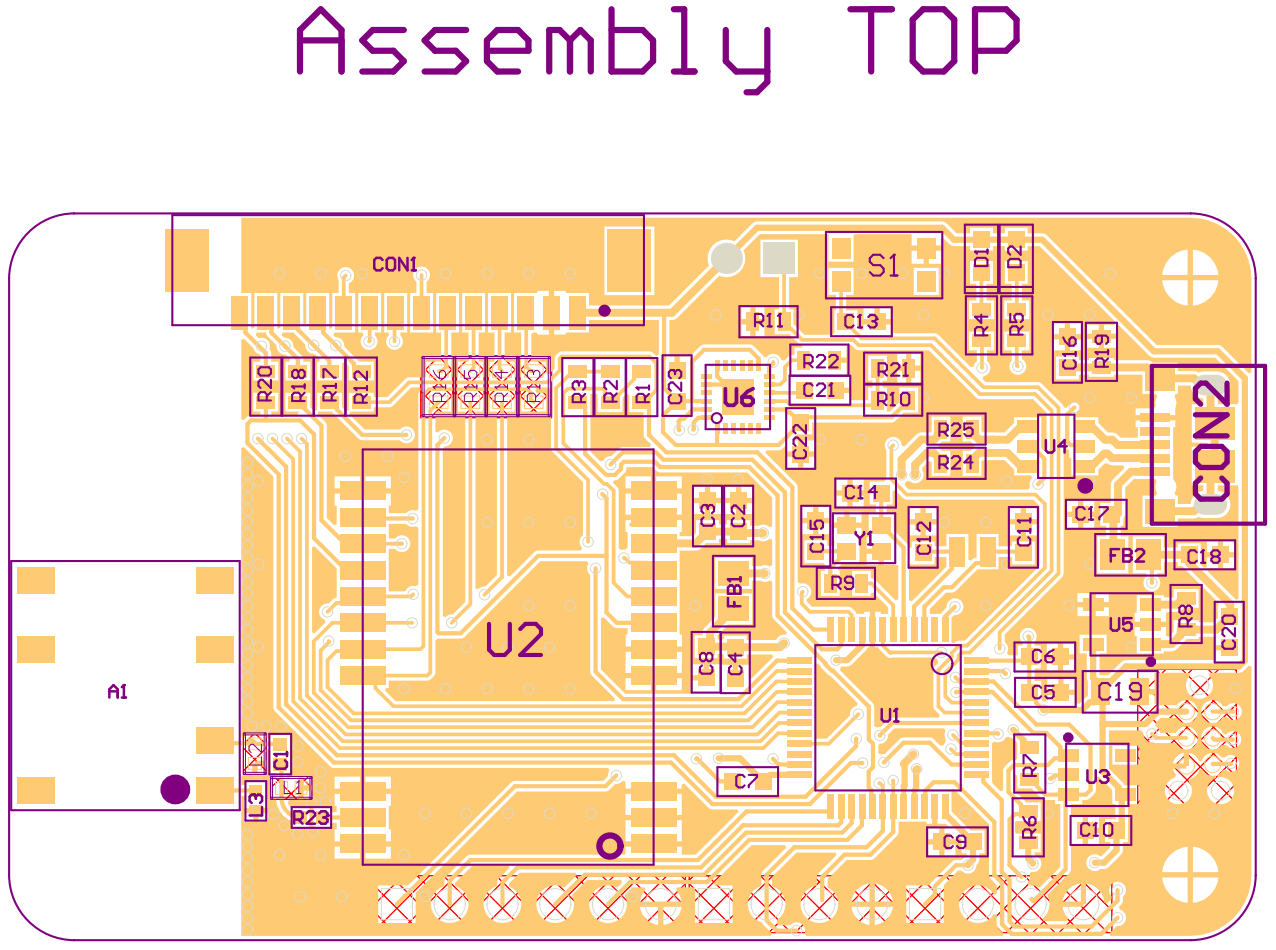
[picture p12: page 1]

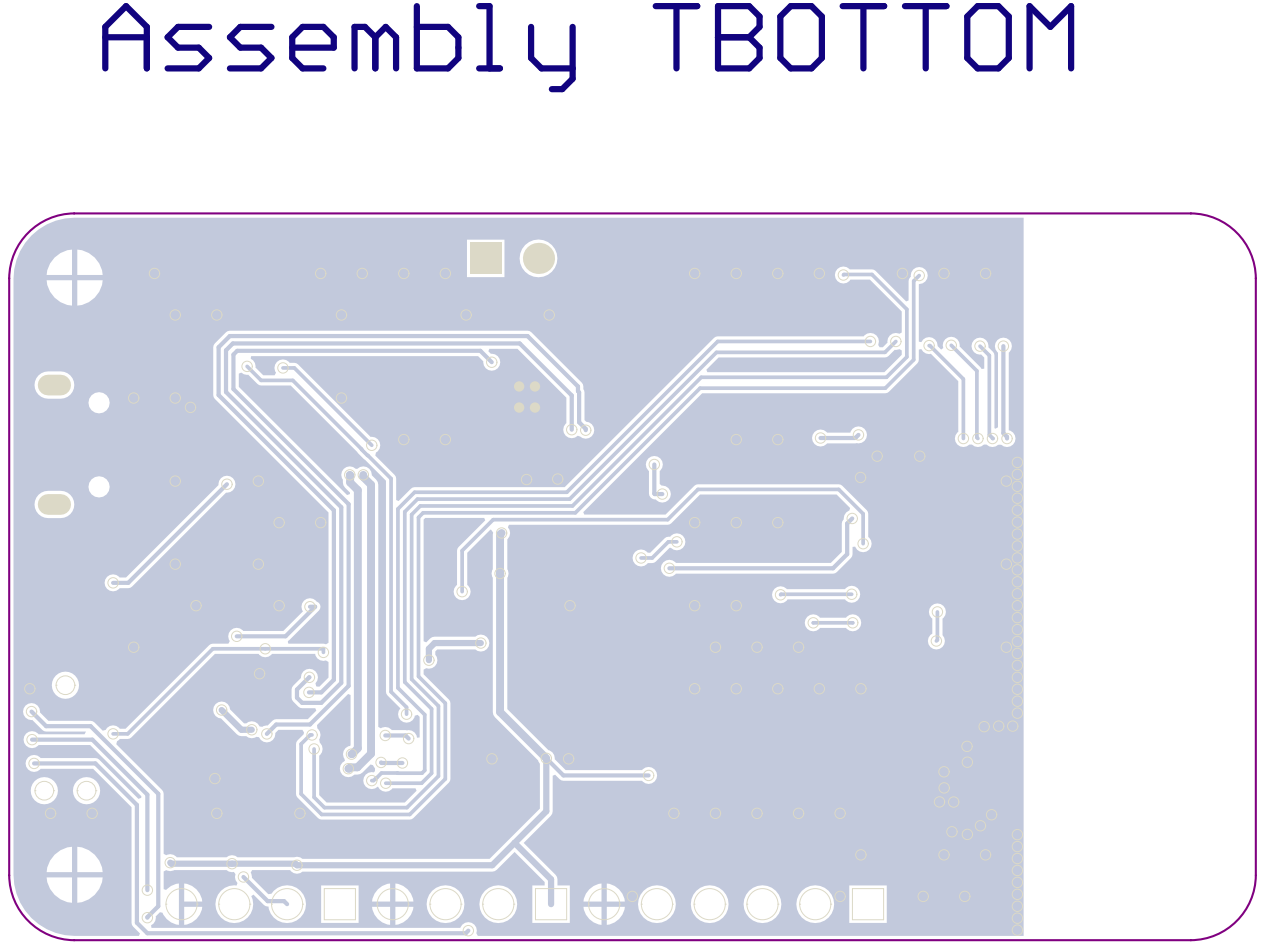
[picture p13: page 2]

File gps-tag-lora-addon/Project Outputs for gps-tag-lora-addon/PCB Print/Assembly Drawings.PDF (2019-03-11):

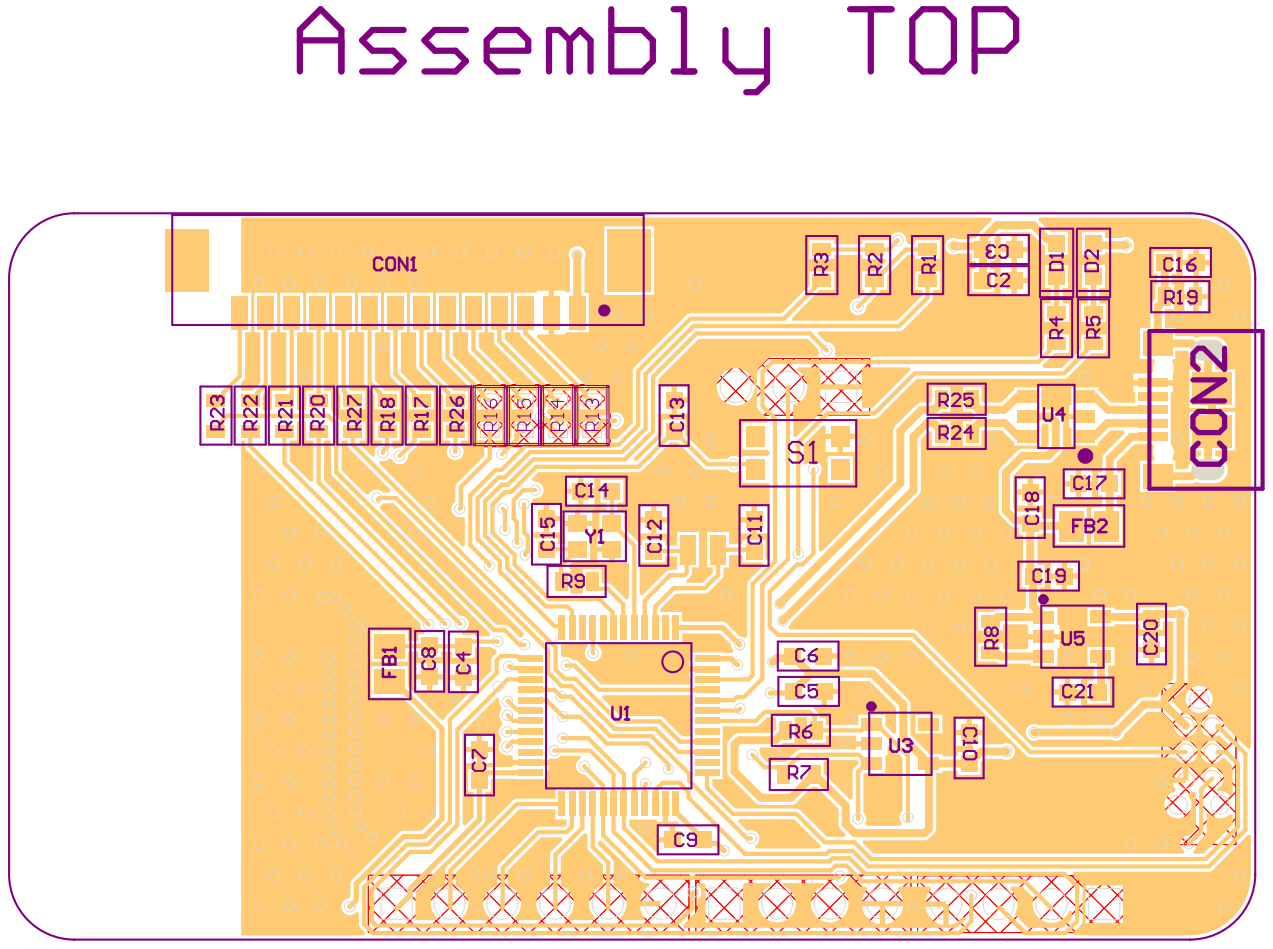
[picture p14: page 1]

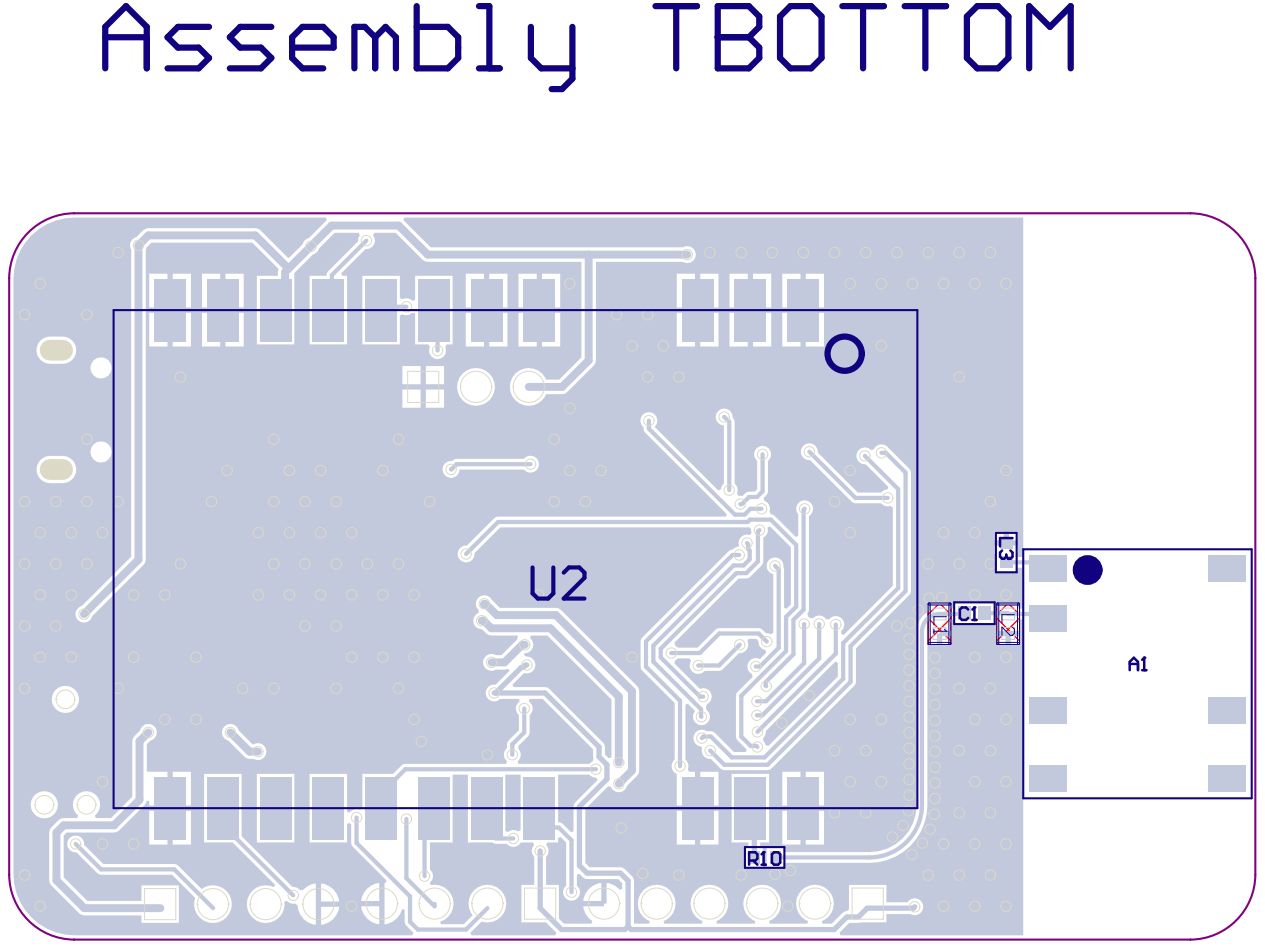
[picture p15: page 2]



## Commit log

2019-03-05 add project
    [532611471.stp, BOM-gps-tag-lora-addon.csv, PAGE1-CONTENT.SchDoc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]
2019-03-11 new version, small modifications v0_2
    [Bill of Materials production-gps-tag-lora-addon(standalone).csv, PAGE2-MCU,LORA.SchDoc, Pick Place for gps-tag-lora-addon(standalone).csv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]
2019-04-04 new v0_2-22S release
    [BOM-gps-tag-lora-addon(standalone).xlsx, BOM-gps-tag-lora-addon.csv, Bill of Materials production-gps-tag-lora-addon(standalone).csv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]
